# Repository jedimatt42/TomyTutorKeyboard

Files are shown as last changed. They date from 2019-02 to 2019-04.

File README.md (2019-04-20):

# TomyTutorKeyboard
A PCBoard design for replacing Tomy Tutor Computer keyboard.

## Status
This is tested. Works great.

## Files

Schematic is here based on KiCAD.

* gerbers - folder with the rendered gerbers
* tomy_tutor_keyboard.scad - OpenSCAD model design file for framing
* tomy_tutor_keyboard.stl - STL file output ready for your favority slicer

# BOM

## 1. Printed Circuit Board

You'll need the bare pcb, see the design files here in this repo.

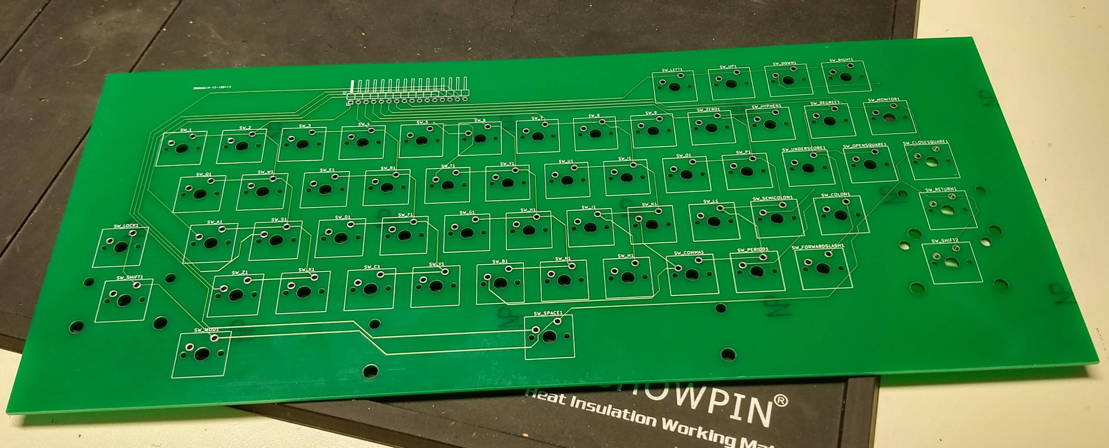
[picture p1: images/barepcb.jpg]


## 2. 57 MX1A-11NW key switches or equivalent:

The pcboard footprint is specific to these switches. But there are some variety that have the same footprint.

[mouser switches](https://www.mouser.com/ProductDetail/540-MX1A-11NW)

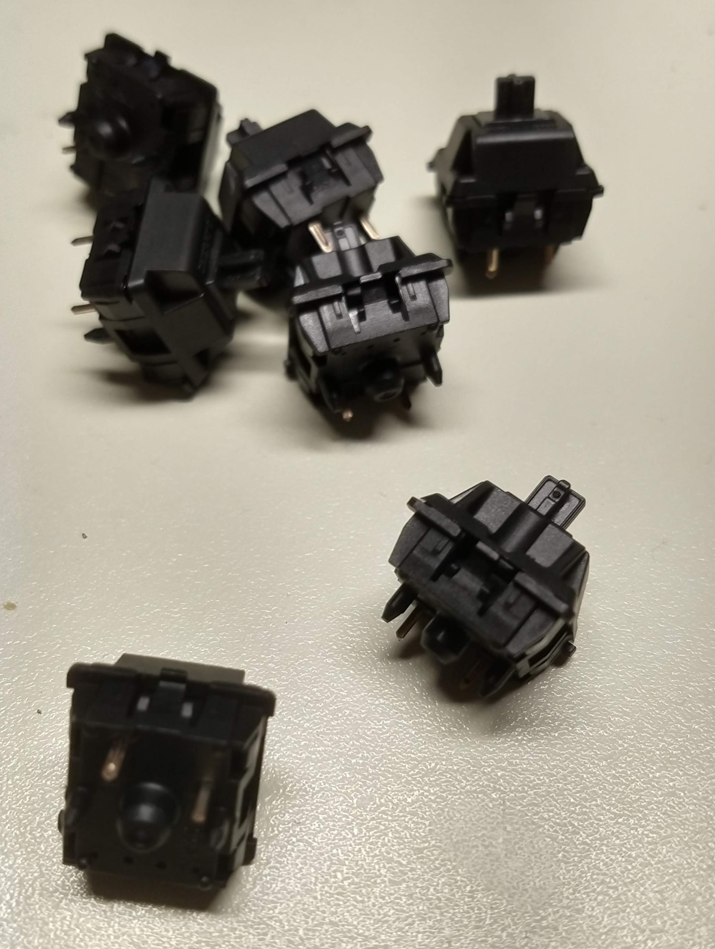
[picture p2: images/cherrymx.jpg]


## 3. set of key stabalizers for the wide keys:

[ebay stabalizers](https://www.ebay.com/itm/322528567052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)

## 4. Cable

16 female to female dupont style jumper wires

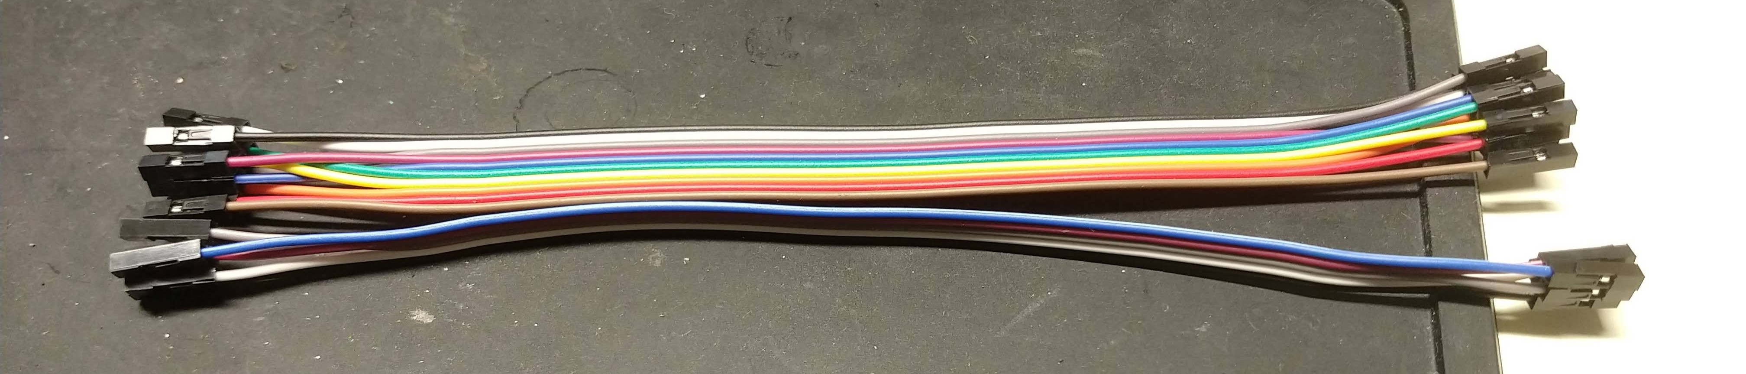
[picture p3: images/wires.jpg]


## 5. 16 pin single inline 2.54mm right angle header

The header on the keyboard pcb is mounted on the underside of the board with the right angle pins facing forward.

## 6. 16 pin single inline 2.54mm straight header

I desoldered and removed the existing film cable connector from the Tomy Tutor motherboard, and replaced it with a row of 16 2.54mm spaced headers.

## 7. Key caps

I used a set of PC keyboard keycaps with a diminutive print. If you can find some with no print, that would be closer to ideal. You'll never find ones that match the Tomy keyboard map.  I found mine on ebay.

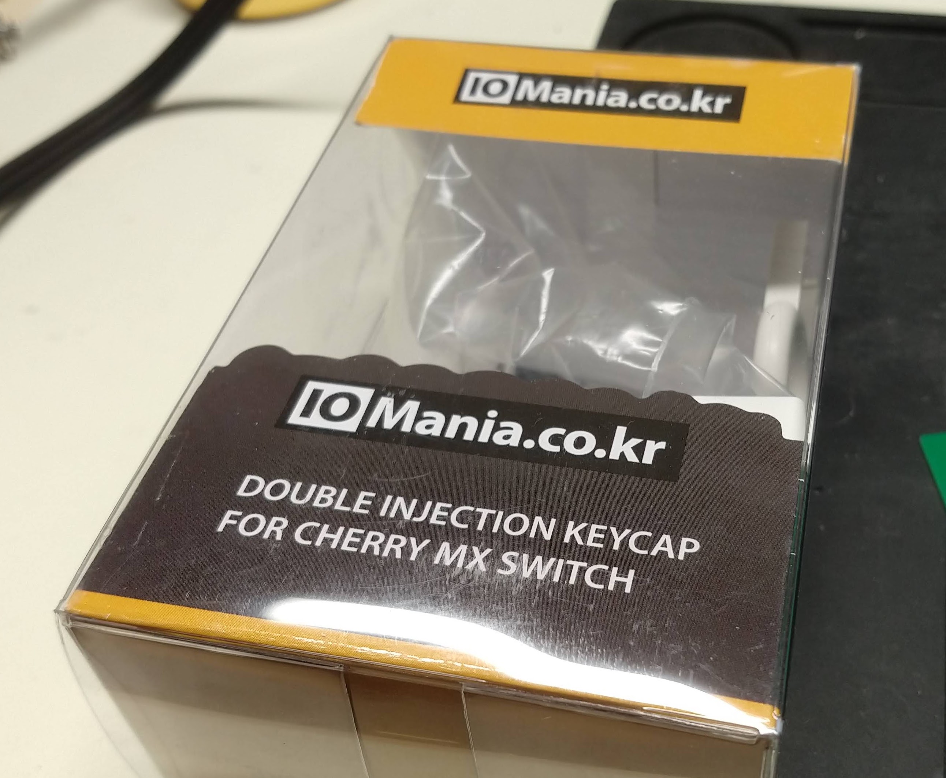
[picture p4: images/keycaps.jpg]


## 8. Transparent adhesive printer sheet. 

I printed my key labels on a sheet of adhesive transparency with a laser printer. Then cut out each label and applied it to the keycaps after they were in place. Not the most ideal.

[amazon - Avery self adhesive laminating sheets](https://smile.amazon.com/gp/product/B00006IC7H/ref=ppx_yo_dt_b_search_asin_title?ie=UTF8&psc=1)

NOTE: with regret, I cannot find the document I created with the custom keycap labels...

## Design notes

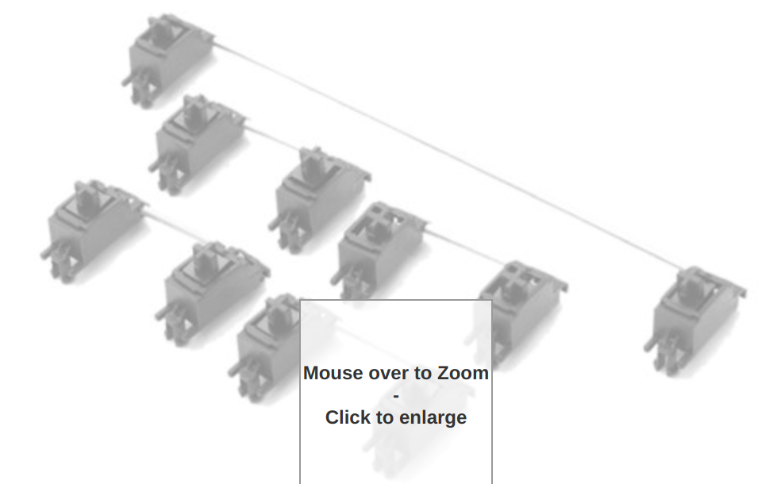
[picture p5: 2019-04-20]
images/cherry-mx-stabalizers.png

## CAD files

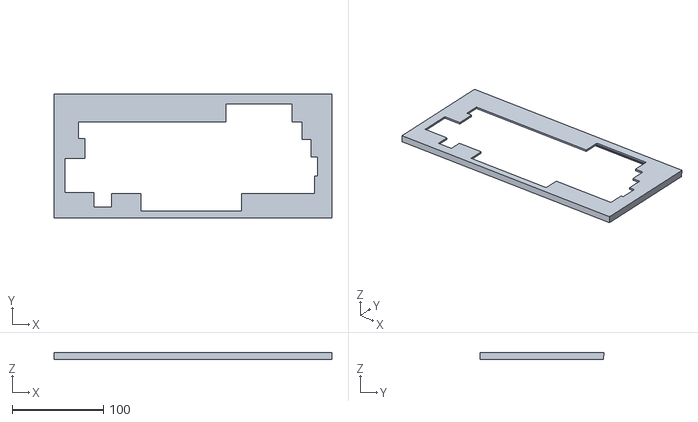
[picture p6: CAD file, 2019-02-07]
tomy_tutor_keyboard.stl
304.0 x 136.0 x 8.00

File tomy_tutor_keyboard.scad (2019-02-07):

// tomy tutor keyboard frame

zz = 8;
iz = 2;
yy = 136;
iy = 128;
xx = 304;
ix = 298;

difference() {
cube([xx, yy, zz],false);

// cut out pcboard 
translate([(xx-ix)/2, (yy-iy)/2, 1])
cube([ix, iy, iz],false);
    
// 
translate([2+((xx-ix)/2), 2+((yy-iy)/2), 0])
cube([ix-4, iy-4, 3*iz],false);

// cut outline of keyboard keys
translate([(xx-ix)/2, (yy-iy)/2,-1])    
linear_extrude(height=10,center=false)
polygon([[9,24], [41,24], [41,8], [60,8], [60,23], [92,23], [92,4], [202,4], [202,23], 
    [249,23], [282,23], [282,42], [285,42], [285,63], [278,63], [278,82],
    [268,82], [268,101], [257,101], [257,121], [185,121],
    [185,101], [24,101], [24, 83], [31, 83], [31,61], [9,61], [9,44]]);

// remove angled edge 1mm at bottom
translate([-1,yy,0])
rotate([0,90,0])
linear_extrude(height=310,center=false)    
polygon([[0,0],[0,-1],[-8,0]]);
}

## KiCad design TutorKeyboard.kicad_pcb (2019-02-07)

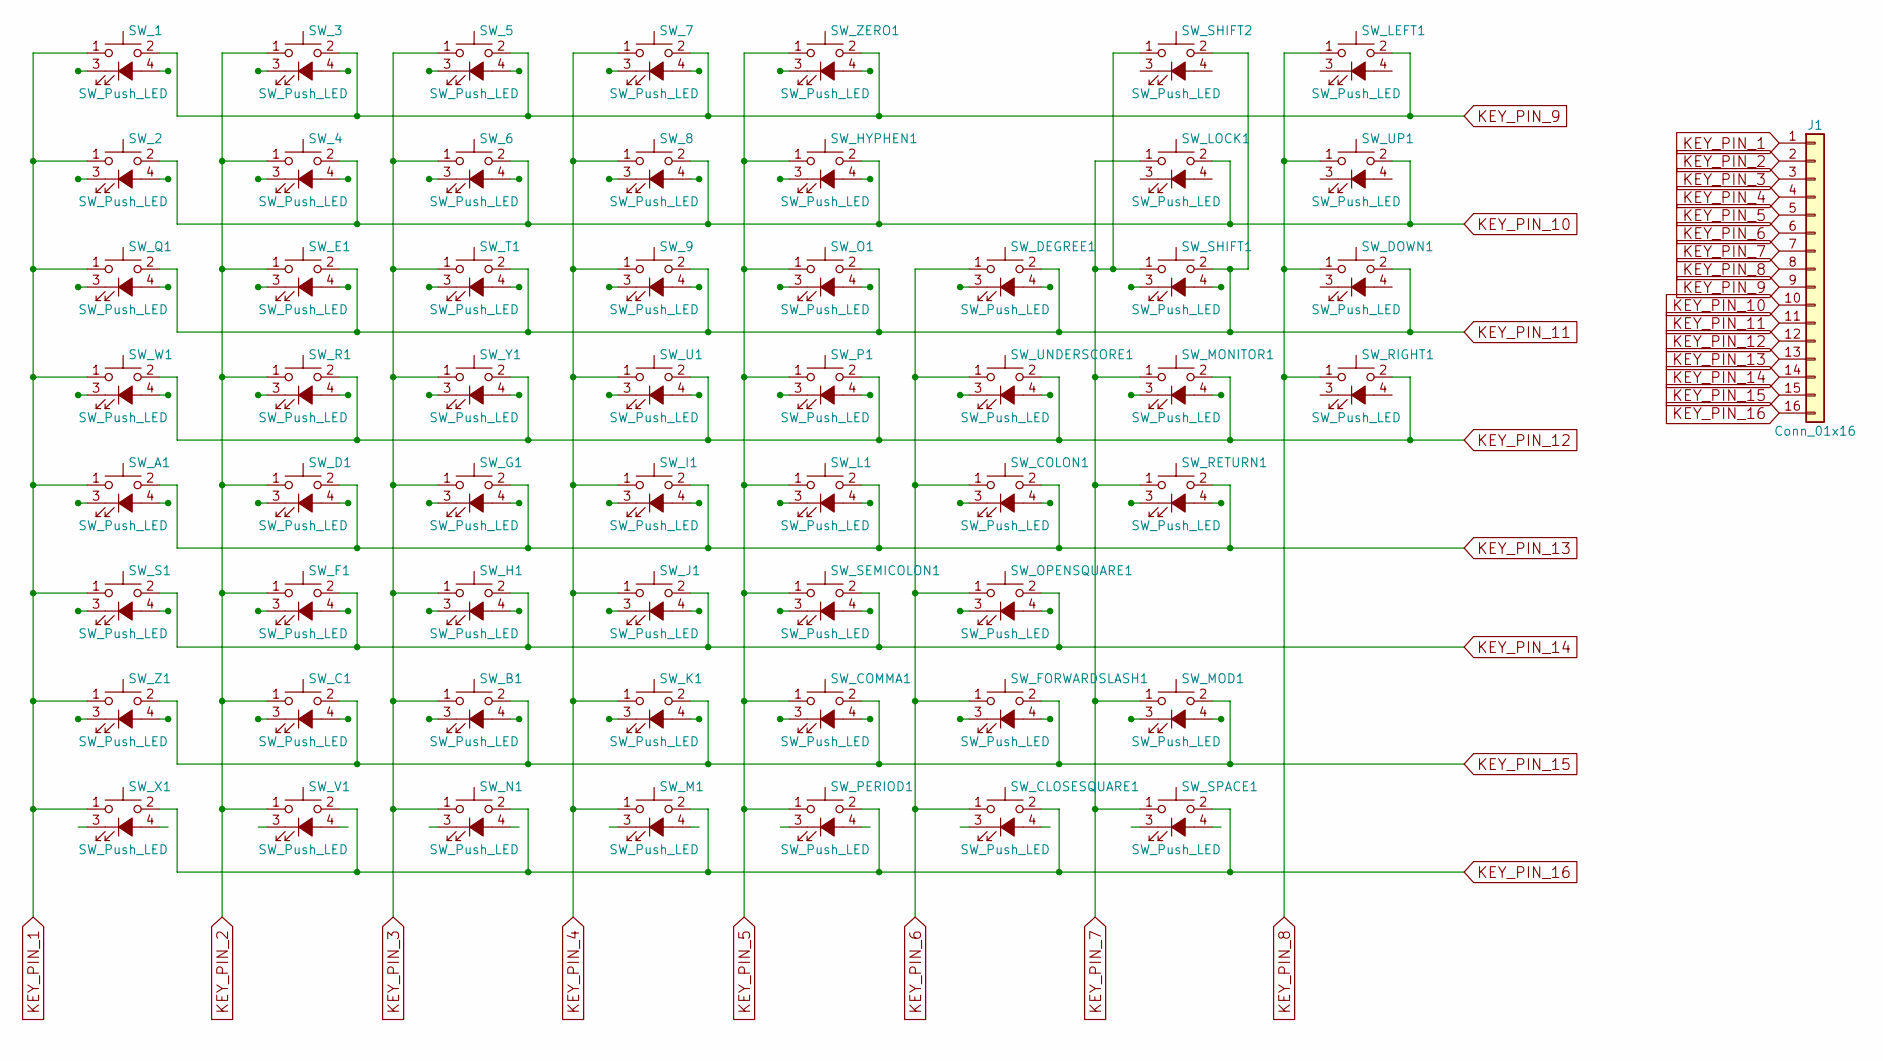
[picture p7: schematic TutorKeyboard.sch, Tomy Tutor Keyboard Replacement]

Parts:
J1: Conn_01x16; Pin_Header_Angled_1x16_Pitch2.54mm
SW_1, SW_2, SW_3, SW_4, SW_5, SW_6, SW_7, SW_8, SW_9: SW_Push_LED; SW_Cherry_MX1A_1.00u_PCB
SW_A1: SW_Push_LED; SW_Cherry_MX1A_1.00u_PCB
SW_B1: SW_Push_LED; SW_Cherry_MX1A_1.00u_PCB
SW_C1: SW_Push_LED; SW_Cherry_MX1A_1.00u_PCB
SW_CLOSESQUARE1: SW_Push_LED; SW_Cherry_MX1A_1.00u_PCB
SW_COLON1: SW_Push_LED; SW_Cherry_MX1A_1.00u_PCB
SW_COMMA1: SW_Push_LED; SW_Cherry_MX1A_1.00u_PCB
SW_D1: SW_Push_LED; SW_Cherry_MX1A_1.00u_PCB
SW_DEGREE1: SW_Push_LED; SW_Cherry_MX1A_1.00u_PCB
SW_DOWN1: SW_Push_LED; SW_Cherry_MX1A_1.00u_PCB
SW_E1: SW_Push_LED; SW_Cherry_MX1A_1.00u_PCB
SW_F1: SW_Push_LED; SW_Cherry_MX1A_1.00u_PCB
SW_FORWARDSLASH1: SW_Push_LED; SW_Cherry_MX1A_1.00u_PCB
SW_G1: SW_Push_LED; SW_Cherry_MX1A_1.00u_PCB
SW_H1: SW_Push_LED; SW_Cherry_MX1A_1.00u_PCB
SW_HYPHEN1: SW_Push_LED; SW_Cherry_MX1A_1.00u_PCB
SW_I1: SW_Push_LED; SW_Cherry_MX1A_1.00u_PCB
SW_J1: SW_Push_LED; SW_Cherry_MX1A_1.00u_PCB
SW_K1: SW_Push_LED; SW_Cherry_MX1A_1.00u_PCB
SW_L1: SW_Push_LED; SW_Cherry_MX1A_1.00u_PCB
SW_LEFT1: SW_Push_LED; SW_Cherry_MX1A_1.00u_PCB
SW_LOCK1: SW_Push_LED; SW_Cherry_MX1A_1.75u_PCB
SW_M1: SW_Push_LED; SW_Cherry_MX1A_1.00u_PCB
SW_MOD1: SW_Push_LED; SW_Cherry_MX1A_1.00u_PCB
SW_MONITOR1: SW_Push_LED; SW_Cherry_MX1A_1.00u_PCB
SW_N1: SW_Push_LED; SW_Cherry_MX1A_1.00u_PCB
SW_O1: SW_Push_LED; SW_Cherry_MX1A_1.00u_PCB
SW_OPENSQUARE1: SW_Push_LED; SW_Cherry_MX1A_1.00u_PCB
SW_P1: SW_Push_LED; SW_Cherry_MX1A_1.00u_PCB
SW_PERIOD1: SW_Push_LED; SW_Cherry_MX1A_1.00u_PCB
SW_Q1: SW_Push_LED; SW_Cherry_MX1A_1.00u_PCB
SW_R1: SW_Push_LED; SW_Cherry_MX1A_1.00u_PCB
SW_RETURN1: SW_Push_LED; SW_Cherry_MX1A_2.25u_PCB
SW_RIGHT1: SW_Push_LED; SW_Cherry_MX1A_1.00u_PCB
SW_S1: SW_Push_LED; SW_Cherry_MX1A_1.00u_PCB
SW_SEMICOLON1: SW_Push_LED; SW_Cherry_MX1A_1.00u_PCB
SW_SHIFT1: SW_Push_LED; SW_Cherry_MX1A_2.25u_PCB
SW_SHIFT2: SW_Push_LED; SW_Cherry_MX1A_2.75u_PCB
SW_SPACE1: SW_Push_LED; SW_Cherry_MX1A_6.25u_PCB
SW_T1: SW_Push_LED; SW_Cherry_MX1A_1.00u_PCB
SW_U1: SW_Push_LED; SW_Cherry_MX1A_1.00u_PCB
SW_UNDERSCORE1: SW_Push_LED; SW_Cherry_MX1A_1.00u_PCB
SW_UP1: SW_Push_LED; SW_Cherry_MX1A_1.00u_PCB
SW_V1: SW_Push_LED; SW_Cherry_MX1A_1.00u_PCB
SW_W1: SW_Push_LED; SW_Cherry_MX1A_1.00u_PCB
SW_X1: SW_Push_LED; SW_Cherry_MX1A_1.00u_PCB
SW_Y1: SW_Push_LED; SW_Cherry_MX1A_1.00u_PCB
SW_Z1: SW_Push_LED; SW_Cherry_MX1A_1.00u_PCB
SW_ZERO1: SW_Push_LED; SW_Cherry_MX1A_1.00u_PCB

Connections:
KEY_PIN_1: J1.1, SW_1.1, SW_2.1, SW_A1.1, SW_Q1.1, SW_S1.1, SW_W1.1, SW_X1.1, SW_Z1.1
KEY_PIN_2: J1.2, SW_3.1, SW_4.1, SW_C1.1, SW_D1.1, SW_E1.1, SW_F1.1, SW_R1.1, SW_V1.1
KEY_PIN_3: J1.3, SW_5.1, SW_6.1, SW_B1.1, SW_G1.1, SW_H1.1, SW_N1.1, SW_T1.1, SW_Y1.1
KEY_PIN_4: J1.4, SW_7.1, SW_8.1, SW_9.1, SW_I1.1, SW_J1.1, SW_K1.1, SW_M1.1, SW_U1.1
KEY_PIN_5: J1.5, SW_COMMA1.1, SW_HYPHEN1.1, SW_L1.1, SW_O1.1, SW_P1.1, SW_PERIOD1.1, SW_SEMICOLON1.1, SW_ZERO1.1
KEY_PIN_6: J1.6, SW_CLOSESQUARE1.1, SW_COLON1.1, SW_DEGREE1.1, SW_FORWARDSLASH1.1, SW_OPENSQUARE1.1, SW_UNDERSCORE1.1
KEY_PIN_7: J1.7, SW_LOCK1.1, SW_MOD1.1, SW_MONITOR1.1, SW_RETURN1.1, SW_SHIFT1.1, SW_SHIFT2.1, SW_SPACE1.1
KEY_PIN_8: J1.8, SW_DOWN1.1, SW_LEFT1.1, SW_RIGHT1.1, SW_UP1.1
KEY_PIN_9: J1.9, SW_1.2, SW_3.2, SW_5.2, SW_7.2, SW_LEFT1.2, SW_ZERO1.2
KEY_PIN_10: J1.10, SW_2.2, SW_4.2, SW_6.2, SW_8.2, SW_HYPHEN1.2, SW_LOCK1.2, SW_UP1.2
KEY_PIN_11: J1.11, SW_9.2, SW_DEGREE1.2, SW_DOWN1.2, SW_E1.2, SW_O1.2, SW_Q1.2, SW_SHIFT1.2, SW_SHIFT2.2, SW_T1.2
KEY_PIN_12: J1.12, SW_MONITOR1.2, SW_P1.2, SW_R1.2, SW_RIGHT1.2, SW_U1.2, SW_UNDERSCORE1.2, SW_W1.2, SW_Y1.2
KEY_PIN_13: J1.13, SW_A1.2, SW_COLON1.2, SW_D1.2, SW_G1.2, SW_I1.2, SW_L1.2, SW_RETURN1.2
KEY_PIN_14: J1.14, SW_F1.2, SW_H1.2, SW_J1.2, SW_OPENSQUARE1.2, SW_S1.2, SW_SEMICOLON1.2
KEY_PIN_15: J1.15, SW_B1.2, SW_C1.2, SW_COMMA1.2, SW_FORWARDSLASH1.2, SW_K1.2, SW_MOD1.2, SW_Z1.2
KEY_PIN_16: J1.16, SW_CLOSESQUARE1.2, SW_M1.2, SW_N1.2, SW_PERIOD1.2, SW_SPACE1.2, SW_V1.2, SW_X1.2

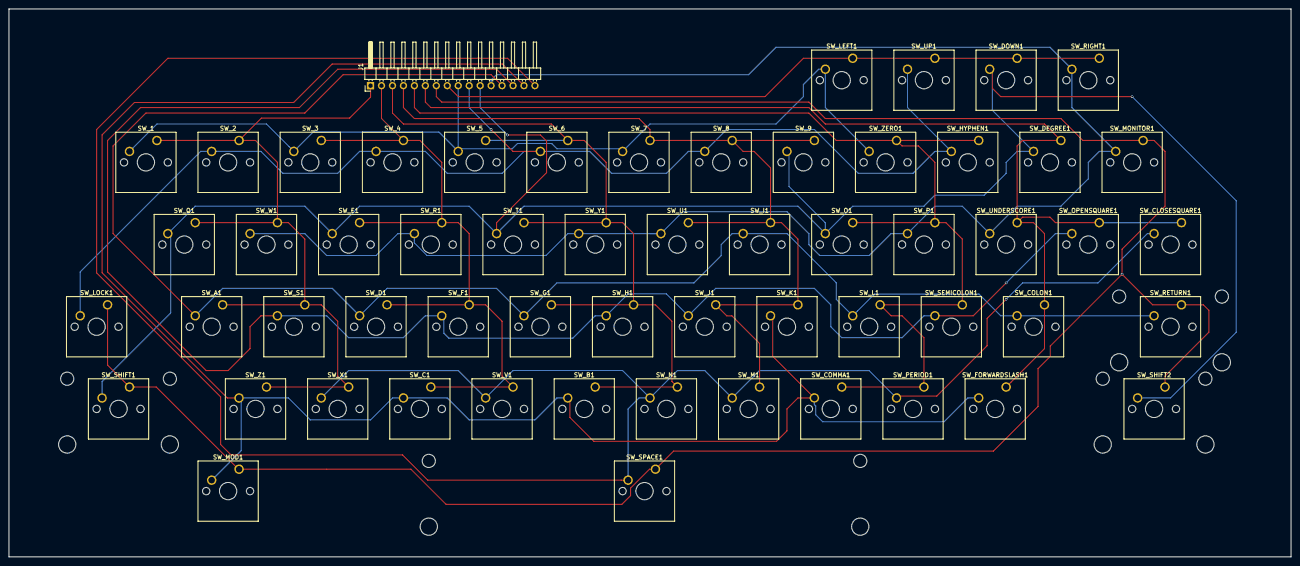
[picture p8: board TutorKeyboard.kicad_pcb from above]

Board: 2 copper layers, 297.2 x 127.0 mm, 58 parts (0 on the bottom side), 16 nets.

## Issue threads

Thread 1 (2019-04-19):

Tutor keyboard layout

ppj34, 2019-04-19:
Hello,

I uploaded and printed the pcb you offer. I would like some details on the editing of the keyboard keys:

Should the switches be soldered or bonded?

For the ribbon that connects the pcb to the connector of the motherboard of the tutor, what did you use please?

Do you have some photos please?

Thank you for your work and in advance your help.

Regards,

jedimatt42, 2019-04-20:
I've updated the README.md to include some photos... and description of assembly and all the parts involved...   https://github.com/jedimatt42/TomyTutorKeyboard/blob/master/README.md

The switches are soldered in place... not sure what you mean by 'bonded'   Glue?  I did not glue them in place.  Just the 2 solder pins per switch.

My original keyboard had been dead for a while, so well before I made this replacement, I removed the original motherboard connector for the film ribbon, and replaced it with standard 2.54mm pitch headers... then I hooked a few switches on a breadboard so I could still press 1, and return and down arrow to get into a game cartridge.  :(   Anyway, so instead of ribbon cable exactly, I just use header jumpers with female dupont connectors on both ends..  The right angle header on the keyboard pcb needs to be on the underside!

ppj34, 2019-04-21:
<span style="font-family:arial,helvetica,sans-serif; font-size:12px">‌Hi,<br>
<br>
Thank you very much for informations. :-)<br>
<br>
I will keep you informed.</span><br>
<br>
<span style="font-family:arial,helvetica,sans-serif; font-size:12px">Regards,<br>
<br>
Pascal Petitjean</span><br>
&nbsp;
<div class="gl_quote" style="margin-top: 20px; padding-top: 5px;">De : "Matthew Splett"<br>
A : "jedimatt42/TomyTutorKeyboard" ,"ppj34" ,"Author"<br>
Envoyé: samedi 20 avril 2019 17:49<br>
Objet : Re: [jedimatt42/TomyTutorKeyboard] Tutor keyboard layout (#1)<br>
&nbsp;
<div class="gl_quoted">
<p>Reopened <a class="issue-link js-issue-link" data-error-text="Failed to load issue title" data-hovercard-type="issue" data-hovercard-url="/jedimatt42/TomyTutorKeyboard/issues/1/hovercard" data-id="435063685" data-permission-text="Issue title is private" data-url="https://github.com/jedimatt42/TomyTutorKeyboard/issues/1" href="https://github.com/jedimatt42/TomyTutorKeyboard/issues/1">#1</a>.</p>

<p style="font-size:small;-webkit-text-size-adjust:none;color:#666;">—<br>
You are receiving this because you authored the thread.<br>
Reply to this email directly, <a href="https://github.com/jedimatt42/TomyTutorKeyboard/issues/1#event-2289615667">view it on GitHub</a>, or <a href="https://github.com/notifications/unsubscribe-auth/AE5675HUOT2B2IWL4JZVKCDPRM3PHANCNFSM4HHCGWNQ">mute the thread</a>.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</p>
</div>

<div class="gl_quoted">&nbsp;</div>
</div>

ppj34, 2019-05-20:
<span style="font-family:arial,helvetica,sans-serif; font-size:12px">H‌i,</span><br>
<br>
Just a few quick news to notice you that the keyboard works very well.<br>
Thank you again for your good work.<br>
<br>
I try to make a nice keyboard and I send you photos as soon as possible ...<br>
<br>
See you soon.<br>
<br>
Pascal Petitjean
<div class="gl_quote" style="margin-top: 20px; padding-top: 5px;">De : "Matthew Splett"<br>
A : "jedimatt42/TomyTutorKeyboard" ,"ppj34" ,"Author"<br>
Envoyé: samedi 20 avril 2019 17:50<br>
Objet : Re: [jedimatt42/TomyTutorKeyboard] Tutor keyboard layout (#1)<br>
&nbsp;
<div class="gl_quoted">
<p>Closed <a class="issue-link js-issue-link" data-error-text="Failed to load issue title" data-hovercard-type="issue" data-hovercard-url="/jedimatt42/TomyTutorKeyboard/issues/1/hovercard" data-id="435063685" data-permission-text="Issue title is private" data-url="https://github.com/jedimatt42/TomyTutorKeyboard/issues/1" href="https://github.com/jedimatt42/TomyTutorKeyboard/issues/1">#1</a>.</p>

<p style="font-size:small;-webkit-text-size-adjust:none;color:#666;">—<br>
You are receiving this because you authored the thread.<br>
Reply to this email directly, <a href="https://github.com/jedimatt42/TomyTutorKeyboard/issues/1#event-2289616243">view it on GitHub</a>, or <a href="https://github.com/notifications/unsubscribe-auth/AE5675EEFWECQPSSFO2AOQTPRM3URANCNFSM4HHCGWNQ">mute the thread</a>.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</p>
</div>

<div class="gl_quoted">&nbsp;</div>
</div>

Closed 2019-04-20.

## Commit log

2018-01-19 slightly modernized.
    [TutorKeyboard.kicad_pcb, TutorKeyboard.sch]
2019-02-07 final bits and artifacts if others want to print boards
    [TutorKeyboard-B.Cu.gbr, TutorKeyboard-B.Mask.gbr, TutorKeyboard-B.SilkS.gbr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]
2019-02-07 add openscad model source, and stl file - probably needs to be cut up for printing
    [tomy_tutor_keyboard.scad, tomy_tutor_keyboard.stl]
